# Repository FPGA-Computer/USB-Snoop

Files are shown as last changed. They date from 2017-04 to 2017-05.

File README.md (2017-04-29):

USB-Snoop A low cost hardware dongle for capturing and analyzing Full Speed (12Mbps) traffic using ARM microcontroller

Project detail: https://hackaday.io/project/20532-usb-packet-snooping

Firmware/ - dongle firmware - Keil MDK

Hardware/ - Eagle CAD schematic, PCB, Sketchup 3D model (zipped)

Windows Software/ - Pellec C

All of software, firmware written by me are licensed under GPL 3.0. Additional incorporated open sourced code are under their own licenses.

Hardware is licensed under CC BY-4.0

https://creativecommons.org/licenses/by/4.0/

Compilers:

Pelles C compiler (freeware): http://www.smorgasbordet.com/pellesc/

Keil's free-to-use professional tool suite - MDK for STM32L0 and STM32F0 http://www2.keil.com/stmicroelectronics-stm32/mdk

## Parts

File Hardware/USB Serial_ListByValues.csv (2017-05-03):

Qty | Value | Part Num | Package | Parts | Note
1 |  | 3X2 HEADER 2MM THROUGH HOLE | 2X03M_TH | J2
1 |  | MICRO USB FEMALE SMT | USB-AB-MICRO-SMD_V03_SMT | J1
1 | 0u1 | 0U1 X7R 0603 | CAPC1608X92N | C5
1 | 1K | 1K 0603 | RESC1608X55N | R4
1 | 1K5 | 1K5 0603 | RESC1608X55N | R1
2 | 1uF | 1UF X7R 0603 | CAPC1608X92N | C3, C4
1 | 12MHz | 12MHZ TC26 | TC26H | X1 | Not needed for PL2303HXD
2 | 22R | 22R 0603 | RESC1608X55N | R2, R3
2 | 22pF | 22PF 0603 | CAPC1608X92N | C1, C2 | Not needed for PL2303HXD
1 | 24LC02 | 24LC02 | TSSOP8 | U2 | Not needed for PL2303HXD
1 | PL2303HX | PL-2303HXD SSOP | SSOP28DB | U1
1 |  | PCB |  |  | https://oshpark.com/shared_projects/XUkCYeOm
1 |  | M1.6 x 12mm screw (DIN912)
1 |  | M1.6 nut (DIN934 M1.6)
1 |  | 0.25" standoff, 1.6mm ID, 3mm OD |  |  | Determined by stacking height of 2mm connectors

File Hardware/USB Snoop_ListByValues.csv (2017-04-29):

Qty | Value | Part Num | Package | Parts
1 |  | Green LED 0603 | SML0603 | LED1
1 |  | 1X04 HEADER 2.54MM | 1X04 | J1
1 |  | 2X3 2MM FEMALE HEADER THROUGH HOLE | 2X03M_TH | J4
3 | 0.1uF | 0U1 0603 | CAPC1608X92N | C3, C4, C7
1 | 1K2 | 1K2 0603 | RESC1608X55N | R1 | > 4.7K for ultra bright LED
2 | 1uF | STOCK: 1UF/10V 20% TDK | CAPC1608X92N | C5, C6
1 | 12MHz | 12MHZ TC26 | TC26H | X1 | https://www.aliexpress.com/item/Free-shiiping-20pcs-2-6-12MHz-Error-20ppm-20pF-Cylinder-quartz-resonator/32323801360.html
2 | 22pF | 22PF 0603 | CAPC1608X92N | C1, C2
1 | 74LVC1G02DBV | 74LVC1G02DBV | SOT23-5 | U3
1 | PN87520-S | Molex PN87520 | PN87520-S | J3
1 | STM32F030F4P6 | STM32F030F4P6 | TSSOP20 | U2
1 | USBA-M-DXSMT2 | Keystone 931 | CHINESE_USB_M_SMT-2 | J2
1 | XC6206P332MR | XC6206P332MR | SOT95P280X135-3N | U1 | Alternative: MCP1700T-3302E/TT
1 | PCB |  |  |  | https://oshpark.com/shared_projects/bEmfHd8b

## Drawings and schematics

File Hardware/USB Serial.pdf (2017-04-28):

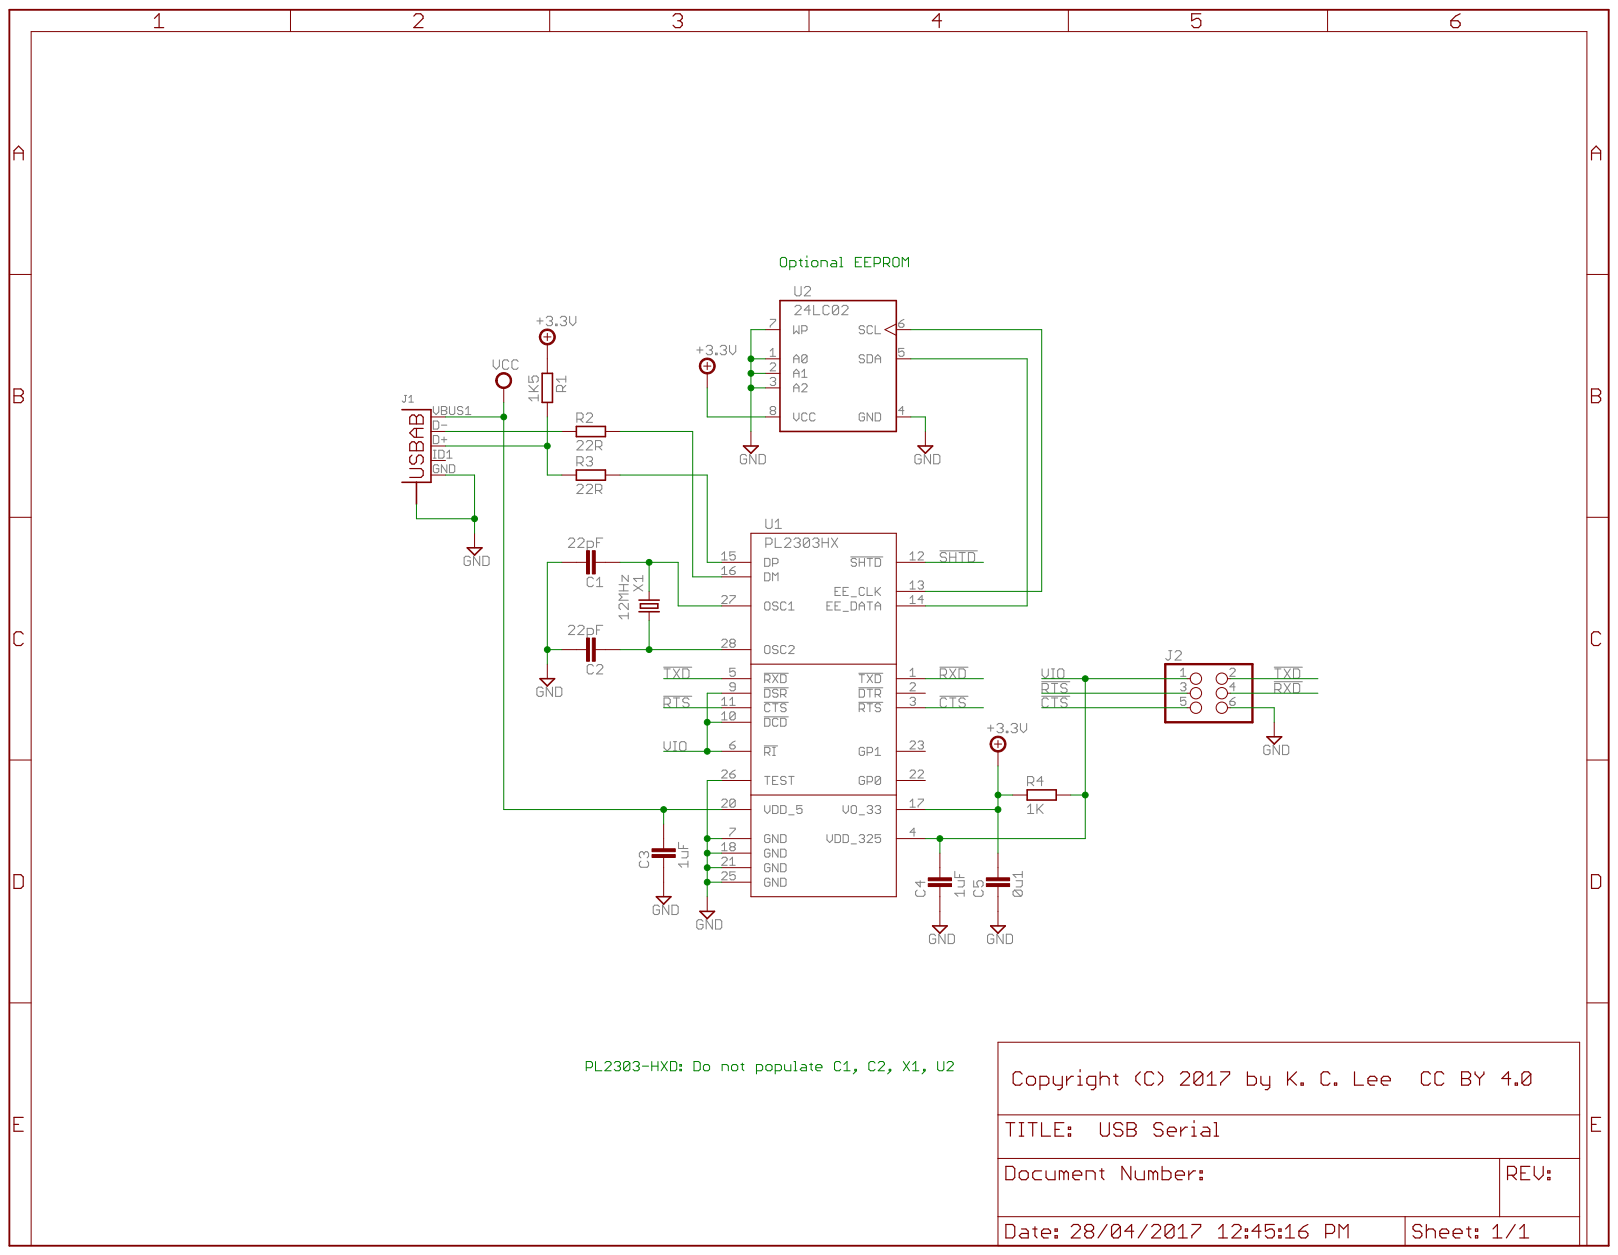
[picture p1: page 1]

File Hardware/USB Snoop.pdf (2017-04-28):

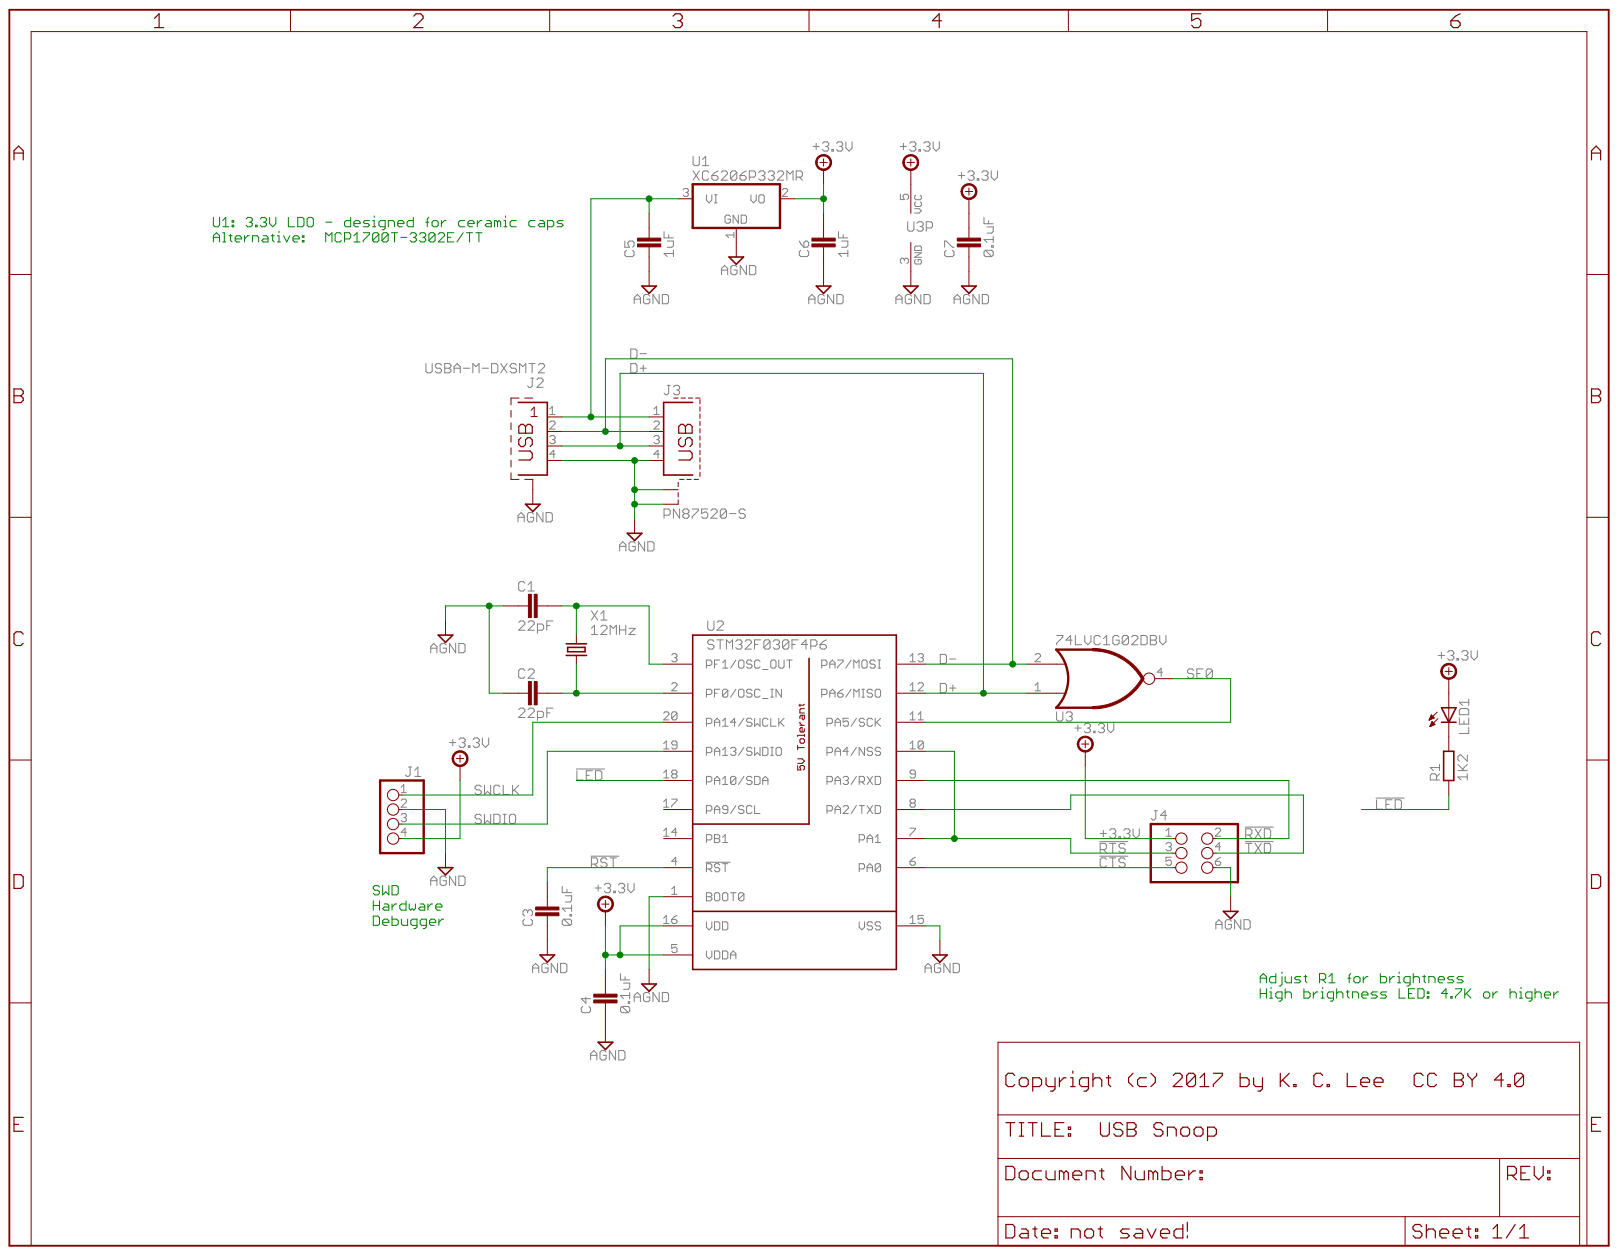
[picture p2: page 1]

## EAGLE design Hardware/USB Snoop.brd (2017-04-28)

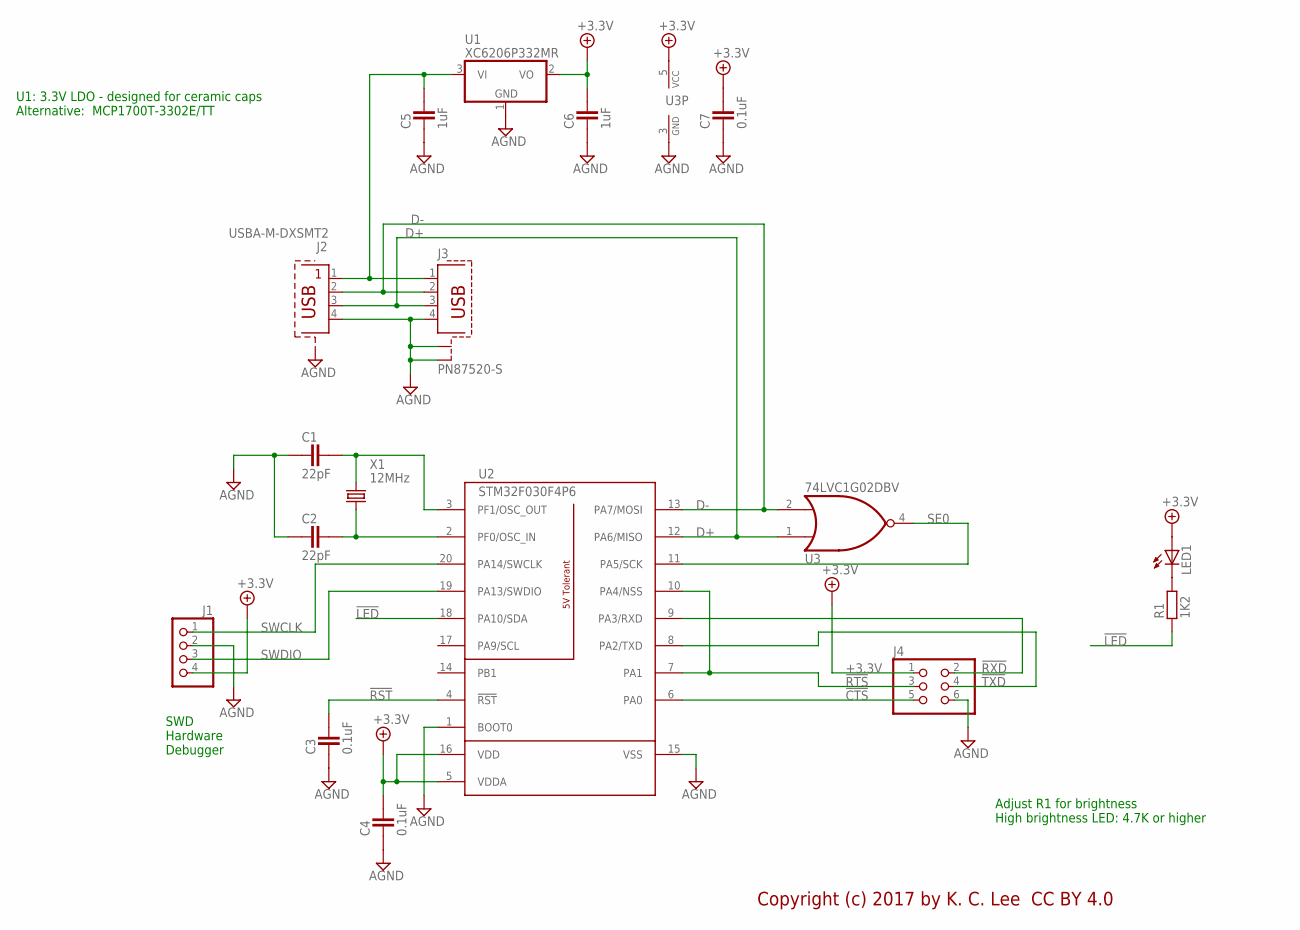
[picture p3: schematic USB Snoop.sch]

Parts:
C1, C2: 22pF; CAPC1608X92N; PARTNO *
C3, C4, C7: 0.1uF; CAPC1608X92N; PARTNO *
C5, C6: 1uF; CAPC1608X92N; PARTNO STOCK: 1UF/10V 20% TDK
J1: PINHD-1X4_2.54; 1X04; PARTNO 1X04 HEADER 2.54MM
J2: USBA-M-DXSMT2; CHINESE_USB_M_SMT-2; PARTNO *
J3: PN87520-S; PARTNO *
J4: PINHD-2X3_2.00; 2X03M_TH; PARTNO *
LED1: LEDSML0603; SML0603; PARTNO *
R1: 1K2; RESC1608X55N; PARTNO *
U1: XC6206P332MR; SOT95P280X135-3N; PARTNO *
U2: STM32F030F4P6; TSSOP20; PARTNO *
U3: 74LVC1G02DBV; SOT23-5; PARTNO *
X1: 12MHz; TC26H; PARTNO *

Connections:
!CTS: J4.5, U2.6 (PA0)
!LED: R1.1, U2.18 (PA10/SDA)
!RST: C3.2, U2.4 (!RST)
!RTS: J4.3, U2.7 (PA1), U2.10 (PA4/NSS)
!RXD: J4.2, U2.9 (PA3/RXD)
!TXD: J4.4, U2.8 (PA2/TXD)
+3.3V: C4.2, C6.2, C7.2, J1.4, J4.1, LED1.A, U1.2 (VO), U2.5 (VDDA), U2.16 (VDD), U3.5 (VCC)
AGND: C1.1, C2.1, C3.1, C4.1, C5.1, C6.1, C7.1, J1.2, J2.4, J2.S1, J2.S2 (S1), J3.4, J3.S1, J3.S2, J4.6, U1.1 (GND), U2.1 (BOOT0), U2.15 (VSS), U3.3 (GND)
D+: J2.3, J3.3, U2.12 (PA6/MISO), U3.1 (I0)
D-: J2.2, J3.2, U2.13 (PA7/MOSI), U3.2 (I1)
unnamed: C2.2, U2.2 (PF0/OSC_IN), X1.2
unnamed: LED1.C, R1.2
unnamed: C1.2, U2.3 (PF1/OSC_OUT), X1.1
SE0: U2.11 (PA5/SCK), U3.4 (O)
SWCLK: J1.1, U2.20 (PA14/SWCLK)
SWDIO: J1.3, U2.19 (PA13/SWDIO)
VUSB: C5.2, J2.1, J3.1, U1.3 (VI)

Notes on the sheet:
SWD Hardware Debugger
Copyright (c) 2017 by K. C. Lee CC BY 4.0
U1: 3.3V LDO - designed for ceramic caps Alternative: MCP1700T-3302E/TT
Adjust R1 for brightness High brightness LED: 4.7K or higher

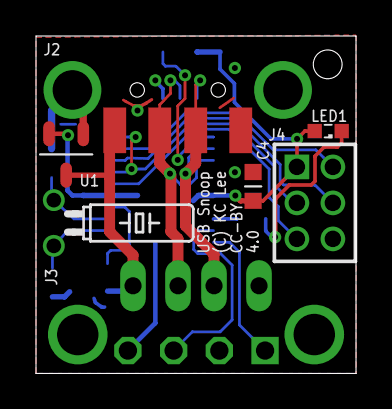
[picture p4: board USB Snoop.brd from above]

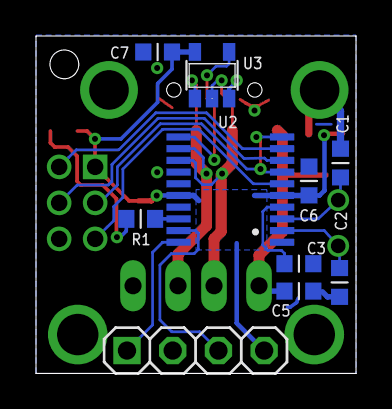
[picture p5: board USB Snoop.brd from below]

Board: 2 copper layers, 17.8 x 18.7 mm, 17 parts (10 on the bottom side), 17 nets.

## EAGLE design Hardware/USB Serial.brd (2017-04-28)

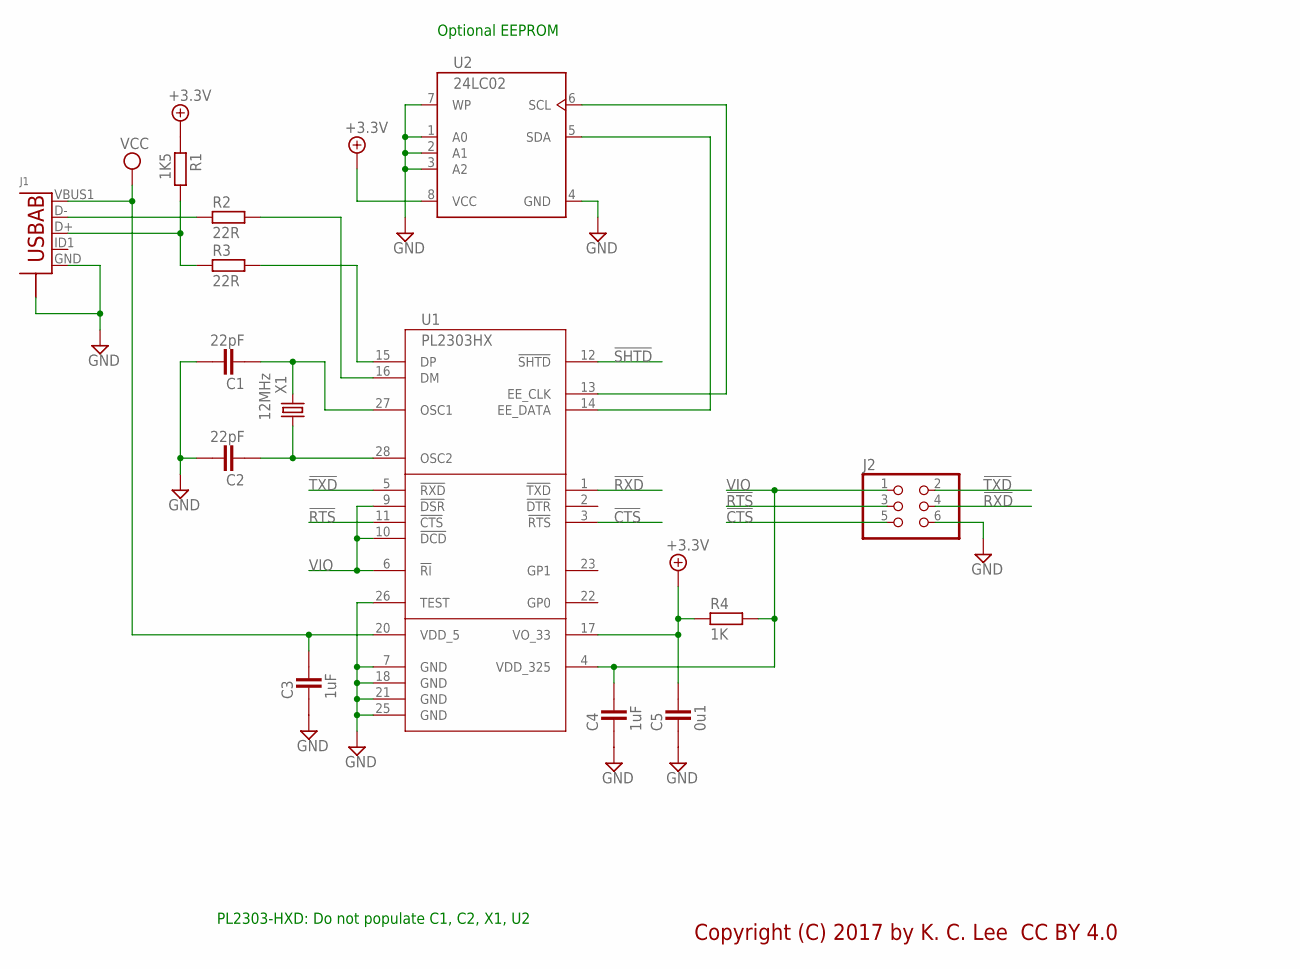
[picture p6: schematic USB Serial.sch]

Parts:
C1, C2: 22pF; CAPC1608X92N; PARTNO 22PF 0603
C3, C4: 1uF; CAPC1608X92N; PARTNO 1UF X7R 0603
C5: 0u1; CAPC1608X92N; PARTNO 0U1 X7R 0603
J1: USB-ABBG-ORG; USB-AB-MICRO-SMD_V03_SMT; PARTNO SMT MICRO USB FEMALE
J2: PINHD-2X3_2.00; 2X03M_TH; PARTNO 3X2 HEADER 2MM THROUGH HOLE
R1: 1K5; RESC1608X55N; PARTNO 1K5 0603
R2, R3: 22R; RESC1608X55N; PARTNO 22R 0603
R4: 1K; RESC1608X55N; PARTNO 1K 0603
U1: PL2303HX; SSOP28DB; PARTNO PL-2303HXD SSOP
U2: 24LC02; TSSOP8; PARTNO 24LC02
X1: 12MHz; TC26H; PARTNO 12MHZ TC26

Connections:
!CTS: J2.5, U1.3 (!RTS)
!RTS: J2.3, U1.11 (!CTS)
!RXD: J2.4, U1.1 (!TXD)
!SHTD: U1.12 (!SHTD)
!TXD: J2.2, U1.5 (!RXD)
+3.3V: C5.2, R1.1, R4.1, U1.17 (VO_33), U2.8 (VCC)
GND: C1.2, C2.2, C3.1, C4.1, C5.1, J1.GND, J1.S1 (S), J1.S2 (S), J1.S3 (S), J1.S4 (S), J2.6, U1.7 (GND), U1.18 (GND), U1.21 (GND), U1.25 (GND), U1.26 (TEST), U2.1 (A0), U2.2 (A1), U2.3 (A2), U2.4 (GND), U2.7 (WP)
unnamed: R3.2, U1.15 (DP)
unnamed: J1.D+, R1.2, R3.1
unnamed: J1.D-, R2.1
unnamed: R2.2, U1.16 (DM)
unnamed: U1.14 (EE_DATA), U2.5 (SDA)
unnamed: U1.13 (EE_CLK), U2.6 (SCL)
unnamed: C1.1, U1.27 (OSC1), X1.2
unnamed: C2.1, U1.28 (OSC2), X1.1
VCC: C3.2, J1.VBUS1 (VBUS), U1.20 (VDD_5)
VIO: C4.2, J2.1, R4.2, U1.4 (VDD_325), U1.6 (!RI), U1.9 (!DSR), U1.10 (!DCD)

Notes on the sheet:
Copyright (C) 2017 by K. C. Lee CC BY 4.0
Optional EEPROM
PL2303-HXD: Do not populate C1, C2, X1, U2

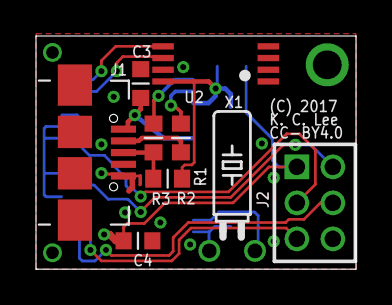
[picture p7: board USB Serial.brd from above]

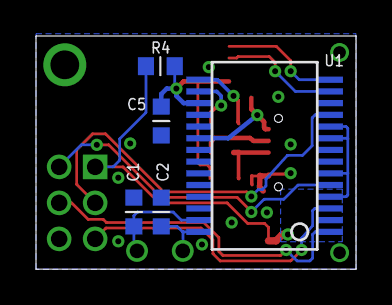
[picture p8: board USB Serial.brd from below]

Board: 2 copper layers, 17.8 x 13.0 mm, 14 parts (5 on the bottom side), 16 nets.

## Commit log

2017-04-28 Initial commit - hardware untested
    [USB Serial.brd, USB Serial.sch, USB Serial_ListByValues.csv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]
2017-04-29 Minor fix up on BOM
    [USB Serial_ListByValues.csv, USB Snoop_ListByValues.csv]
2017-05-03 Update PCB BOM
    [USB Serial_ListByValues.csv]
